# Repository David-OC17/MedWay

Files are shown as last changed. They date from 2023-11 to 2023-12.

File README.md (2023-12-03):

<p align="center">
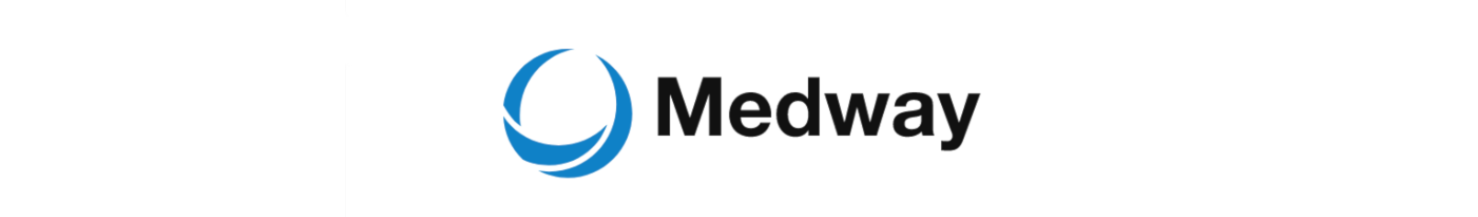
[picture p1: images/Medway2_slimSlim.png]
  
</p>

# MedWay

MedWay: An IoT system for tracking medicines and vaccines from production to use, ensuring their safety and integrity, promoting global health security through transparency and accountability.

## Problem at hand

Ensuring the optimal preservation of medicines and vaccines necessitates strict control over various factors such as temperature and humidity. It is crucial to maintain these conditions to guarantee the products reach their final destination in optimal condition. For pharmaceuticals, particularly those from smaller organizations with limited budgets, effective regulation and tracking become essential to identify instances of mishandling and eliminate potentially compromised batches.

Our proposed system addresses the challenges associated with the mismanagement of vaccines and pharmaceutical drugs, especially prevalent in smaller organizations lacking extensive monitoring infrastructure for their cold chain.

The developed system offers a cost-effective and scalable solution for monitoring batch conditions during transportation. It generates insightful reports to assess potential issues in the transportation process, facilitating the identification and segregation of potentially compromised batches from the rest.

<p align="center">
We combine several technologies and tools in order to produce a valuable and useful system.
</p>

<p align="center">
<a href="https://www.python.org" target="_blank" rel="noreferrer">
python 
</a>
<a href="https://aws.amazon.com/" target="_blank" rel="noreferrer">
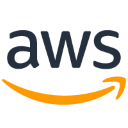
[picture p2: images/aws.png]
 
</a>
<a href="https://flet.dev/" target="_blank" rel="noreferrer">
python 
</a>
<a href="https://platformio.org/" target="_blank" rel="noreferrer">
python 
</a>
<a href="https://xgboost.readthedocs.io/en/stable/#" target="_blank" rel="noreferrer">
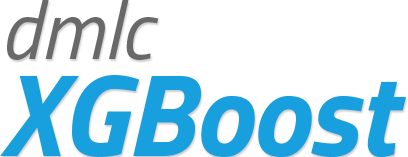
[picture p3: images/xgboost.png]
 
</a>
<a href="https://www.mysql.com/" target="_blank" rel="noreferrer">
python
</a>
<a target="_blank" rel="noopener noreferrer nofollow" href="https://camo.githubusercontent.com/2ecad22021fc13e37458a8d2b508a47352c096930f163927cb191353106f9309/68747470733a2f2f74656368737461636b2d67656e657261746f722e766572636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">
icon
</a>
</p>

## Subparts of the system

### Data acquisition

The data acquisition module is based on a ESP-32 micro-controller, using several sensors to acquire temperature, humidity, acceleration and position. We transfer the data to a computer that acts as a local server using Ubuntu, and temporarily store the data from the N modules running inside medicine/vaccine batches.

<p align="center">
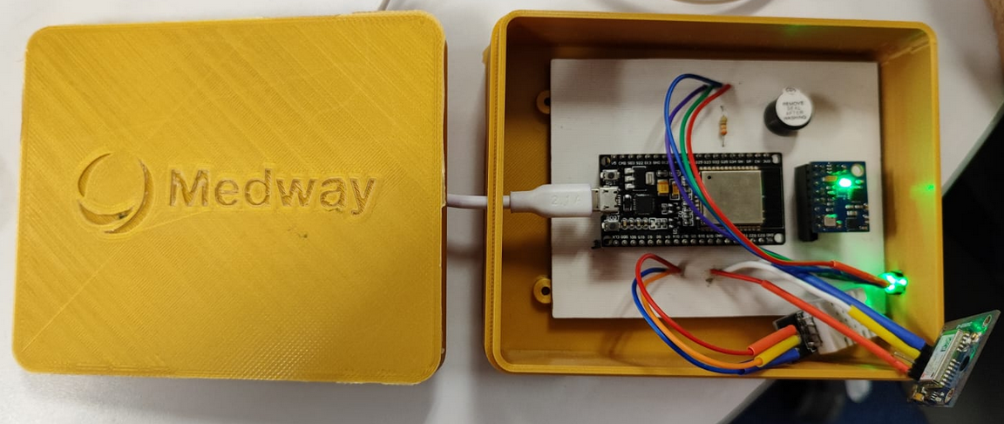
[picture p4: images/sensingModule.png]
  
</p>

### Databases

There are two main types of databases used in this system. The main one is based on MySQL, and is made to be set up on AWS and on a local server. The second one is for storing the reports, result of the daily analysis of data; we use S3 AWS service for this purpose.

### Analysis

The data is analyzed using Lambda functions inside AWS, which run an XGBoost model created via Python. **XGBoost**, short for eXtreme Gradient Boosting, is a powerful and efficient machine learning algorithm that belongs to the ensemble learning category.

<p align="center">
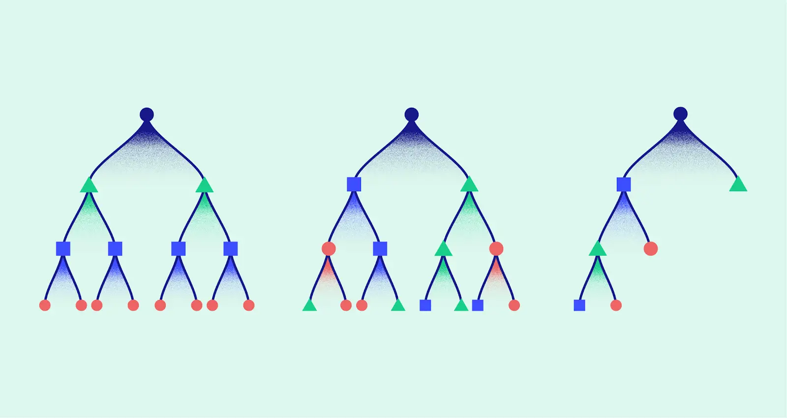
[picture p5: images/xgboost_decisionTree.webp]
  
</p>

The model fits the dataset particularly well, as well as the decisions involved in analyzing the relationships between the main data points of temperature, humidity and UV-light, and its connection to the state of a batch of drugs. Since the connections between the conditions that the batch experiences and the state of the batch itself may be though as a decision tree, where one observes which conditions have been met and which have not, then XGBoost, apart from its robustness, is a good tool for the job.

<!-- Include image of the sensing module, once done -->

### Web and mobile application

The web and mobile app is done via Flet. In the app there are 3 submenus, an introduction, one for downloading the PDF reports, and one that shows a table of the last 30 readings received from the modules.

The app may also be accessed via a phone by generating an QR code that may be scanned using a phone, and will open up the equivalent UI that is generated in the web, inside the Flet app.

## Quick-start guide

To be able to use the implementation developed in this repository you will need to do several things. 

1. Set up your AWS account with the appropriate connections between RDS, S3 and Lambda, in order to run everything on the cloud.

2. Build the physical sensor and receiving modules, from the provided diagram.

3. Install Python3 and all the requirements, via the following command:
```bash
pip3 install -r requirements.txt
```

4. (Optional) Download Flet to your phone (via [AppStore](https://apps.apple.com/mx/app/flet/id1624979699) or PlayStore) in order to be able to access the application from you mobile. Scan the following image to download the app:
<p align="center">
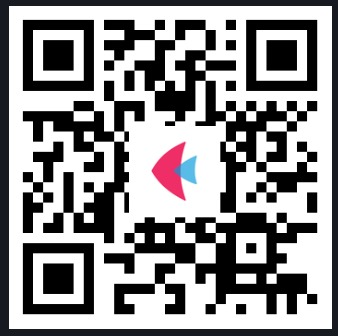
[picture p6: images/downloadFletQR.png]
  
</p>

5. Create `.env` files for saving your passwords and the rest of the variables necessary for connecting to the database services, something with the following type of format:
```python
CLOUD_HOST = 'aws.host.access_point/...'
CLOUD_USER = 'user'
CLOUD_PASSWORD = '123ABC'
# continue declaring the variables
```

6. Create the database for temporary data saving.

7. Create the necessary tables inside the two databases.
```bash
cd databases
python3 createSQL.py
```
8. Set up the WiFi connection to the sensing module and start pulling data. 

9. Wait for the main actions to occur, sending information to the cloud database, generating the reports and seeing the results via the web/mobile app.

To familiarize yourself with the whole system, use the tests inside the `./test/` directory. Also, use the tests to try your local set-up before trying to run the complete system.

<!-- ## Testing

### AWS
In order to test the deployment of the Lambda function before uploading to AWS you may use the [SAM](https://docs.aws.amazon.com/serverless-application-model/latest/developerguide/install-sam-cli.html) locally. -->

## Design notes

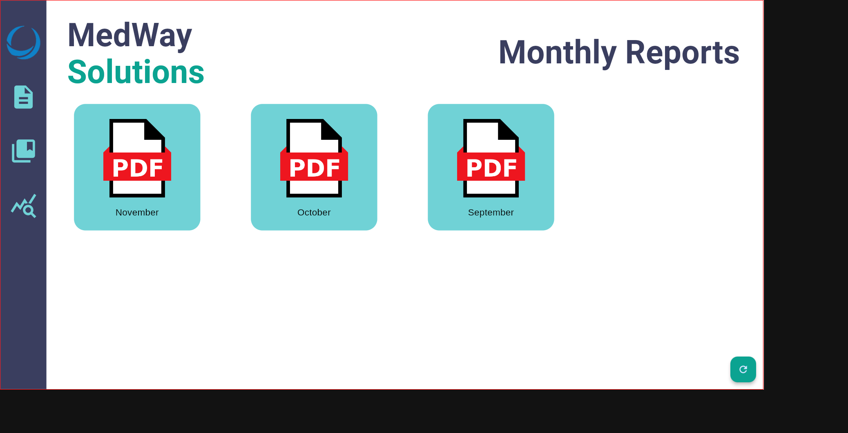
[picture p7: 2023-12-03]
images/monthly_reports.png

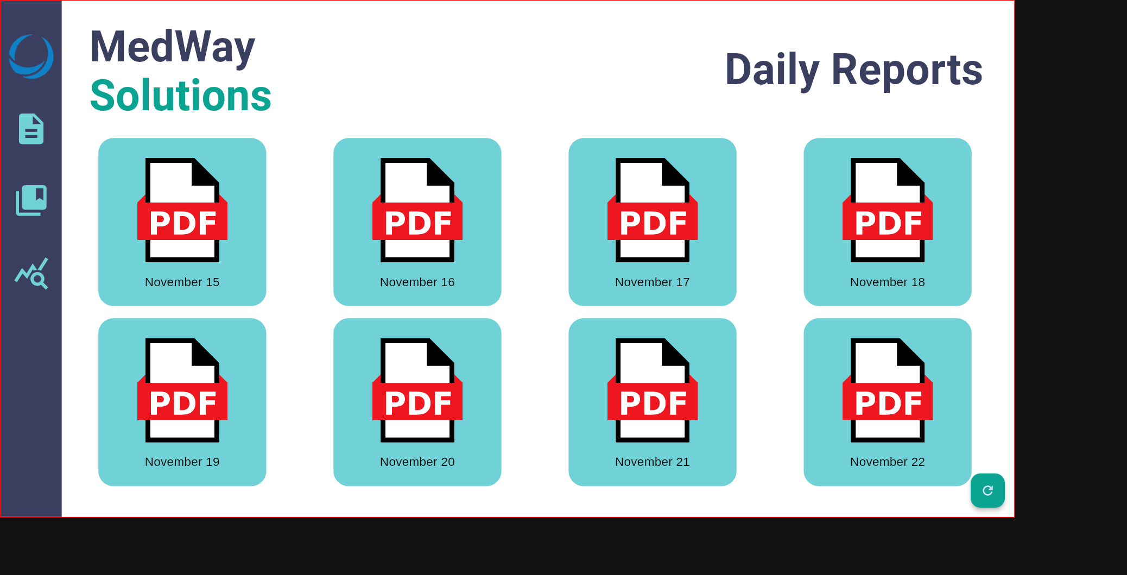
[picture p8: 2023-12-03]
images/daily_reports.png

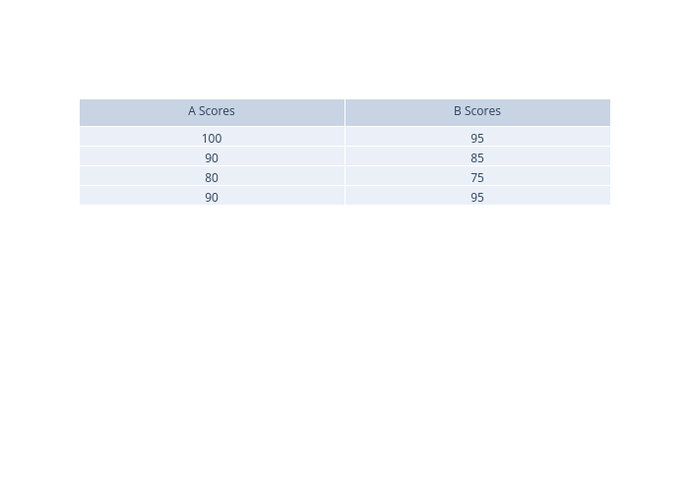
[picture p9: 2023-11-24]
test/reportGenerator/table_image.png

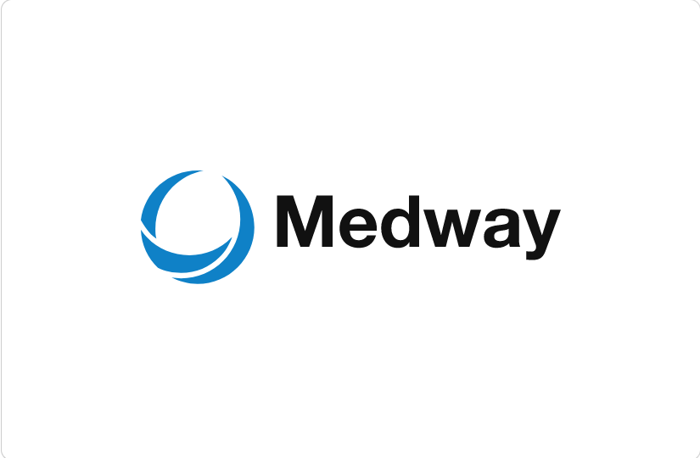
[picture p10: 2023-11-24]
images/Medway2.png

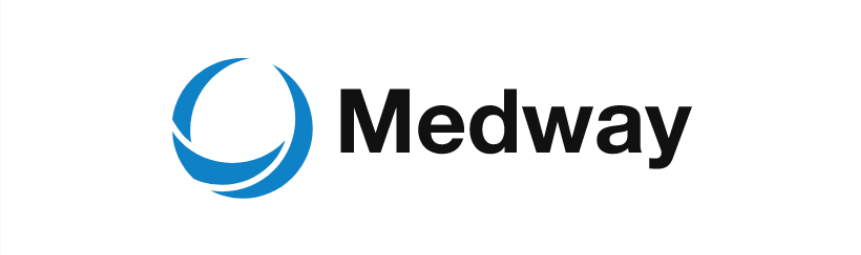
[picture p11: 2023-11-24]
images/Medway2_slim.png

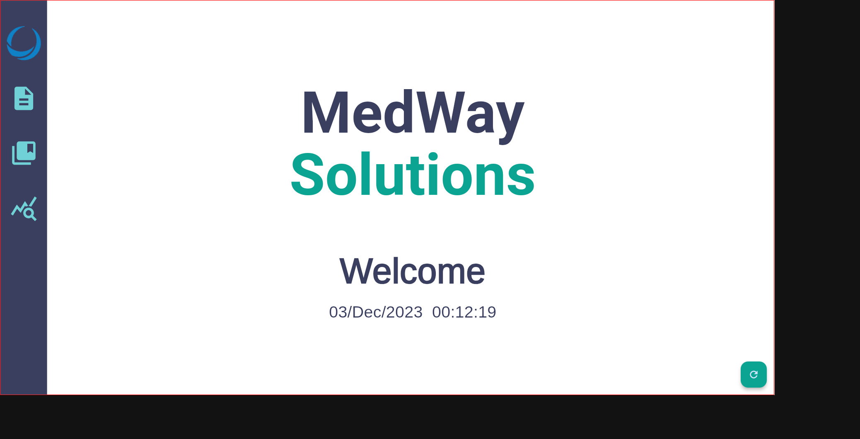
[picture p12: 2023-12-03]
images/home.png

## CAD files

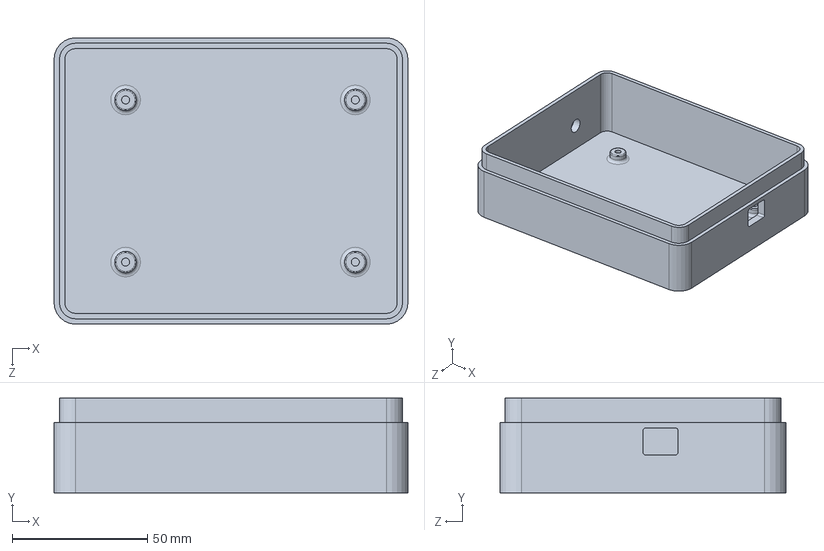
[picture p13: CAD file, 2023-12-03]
dataAcquisition/PCB/SolidCase/Case.SLDPRT
131.0 x 35.0 x 106.0 mm

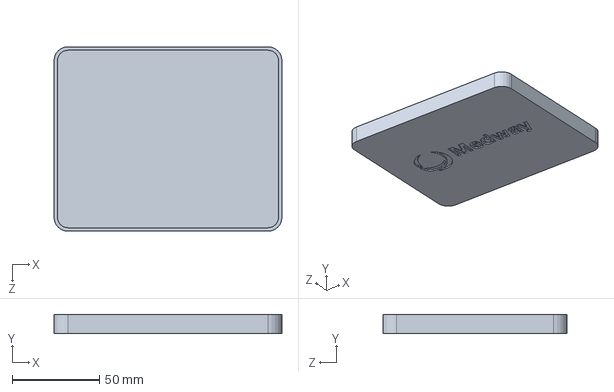
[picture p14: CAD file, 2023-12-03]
dataAcquisition/PCB/SolidCase/Top.SLDPRT
131.0 x 11.0 x 106.0 mm

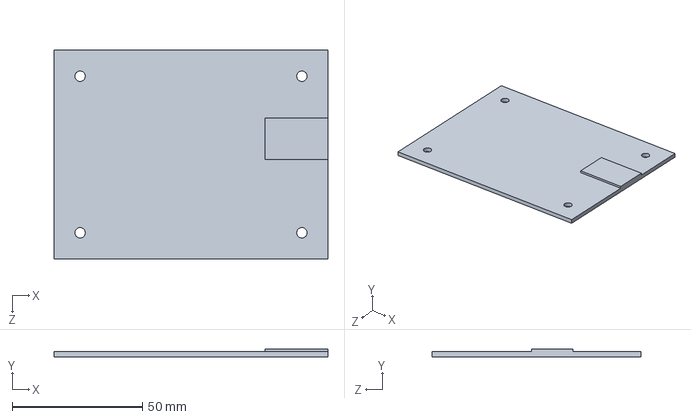
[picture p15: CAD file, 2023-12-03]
dataAcquisition/PCB/SolidCase/Baquela.SLDPRT
105.0 x 3.00 x 80.0 mm

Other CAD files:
dataAcquisition/PCB/SolidCase/Case.STL
dataAcquisition/PCB/SolidCase/Top.STL

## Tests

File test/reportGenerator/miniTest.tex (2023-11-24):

% Use this simple file in order to test basic compilation capabilities of pdflatex in your computer/server

\documentclass{article}
\usepackage{hyperref}
\begin{document}
Hello world \LaTeX

\url{https://linuxconfig.org}
\end{document}

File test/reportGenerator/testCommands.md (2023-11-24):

# Test commands for LaTeX report creation

## Quick test

Compile the `miniTest.tex` file present in this directory by using the command:
```bash
pdflatex -shell-escape miniTest.tex
```

## More extense test

To be able to create the `.pdf` files as needed, verify that `pdflatex` command is working by
compiling the `dailyReportTemplate_test.tex` file present in this directory. (Temporarly take the file to `/analysis/templates/` to avoid having to pass the contents of the placeholders if so is needed, and avoiding having to change the routes to the images.) Run the following command from the terminal:
```bash
# If in Linux
pdflatex -shell-escape dailyReportTemplate_test.tex

# If in Windows
pdflatex dailyReportTemplate_test.tex
```

_Note:_ to test full compilation (with placeholders included) from Python3, run the `reportGenerator.py` file.

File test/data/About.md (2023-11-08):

# Test data

Save testing data only in this directory. 
To generate more data, use /randomTestData/generate_random_data.py

_This file is included in order for the data/ directory to show in the repository._

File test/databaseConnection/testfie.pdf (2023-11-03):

# TEST FILE

Test connection to the cloud by uploading this file. Remove after

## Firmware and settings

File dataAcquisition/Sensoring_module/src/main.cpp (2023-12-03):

#include <Arduino.h>
#include <DHT.h>
#include <TinyGPS++.h>
#include "MPU6050_6Axis_MotionApps20.h"
#include "WiFi.h"

// MACROS
#define DHT_PIN 4
#define DHTTYPE DHT22
#define MPU_INTERRUPT_PIN 27
#define EN_LED 0
#define RED 27
#define GREEN 14
#define BLUE 12
#define BUZZER 13
 
// Constants
const int time2send = 3000;
const int time2sample_dht = 1000;

// Flags
bool wifi_connected = false;
bool mpu_connected = false;

// Sensores
DHT dht(DHT_PIN, DHTTYPE, 22);
TinyGPSPlus gps;
MPU6050 mpu;

// GLOBAL VARS FOR TELEMETRY //
// DHT vars
float hum, temp;

// GPS vars
float lat, lon;
float meters = 0;
uint8_t sats = 0;

// MPU Control vars
bool dmp_ready = false;
uint8_t device_status;
uint8_t interrupt_status;
uint8_t fifoBuffer[64];
uint16_t packet_size;
uint16_t fifo_count;

// DMP Vars
Quaternion q;
VectorInt16 aa;     // Raw acceleration from the sensor
VectorInt16 aaReal;
VectorFloat gravity;
float ypr[3];       // Yaw, Pitch, Roll
float average_array[50];
float mean_accel;
uint8_t accel_count;

// Time management
unsigned long time_aux = 0;

// Send data
String data = "";

///// MPU INTERRUPT /////////////////////////
volatile bool mpu_interrupt = false;
void dmpDataReady(){
  mpu_interrupt = true;
}
/////////////////////////////////////////////

void getGpsInfo(){
  char c = Serial2.read();
      if (gps.encode(c)){   // If a valid sentence comes in get data
        lat = gps.location.lat();
        lon = gps.location.lng();
        meters = gps.altitude.meters();
        sats = gps.satellites.value();
      }
}

void getMpuData(){
  // If dmp was configured succesfully read available packet to fifo buffer
  if(mpu.dmpGetCurrentFIFOPacket(fifoBuffer)){
      // Get yaw/pitch/roll in array
      mpu.dmpGetQuaternion(&q, fifoBuffer);
      mpu.dmpGetGravity(&gravity, &q);
      mpu.dmpGetYawPitchRoll(ypr, &q, &gravity);

      // Get acceleration
      mpu.dmpGetAccel(&aa, fifoBuffer);
      mpu.dmpGetLinearAccel(&aaReal, &aa, &gravity);   // For our needs aaReal is better because it depreciates the constant effect of gravity
      
      // Average
      mean_accel = (aaReal.x + aaReal.y + aaReal.z) / 3;
  }
}

void updateRGBStat(){
  if(wifi_connected && mpu_connected){
    Serial.println("All working fine");
    analogWrite(RED, 0);     // GREEN (working fine)
    analogWrite(GREEN, 255);
    analogWrite(BLUE, 0);
  }else if(wifi_connected && !mpu_connected){
    analogWrite(RED, 255);     // PURPLE
    analogWrite(GREEN, 0);
    analogWrite(BLUE, 255);
  }else if(!wifi_connected && mpu_connected){
    analogWrite(RED, 0);     // GREEN UPDATE
    analogWrite(GREEN, 255);
    analogWrite(BLUE, 0);
  }else{
    analogWrite(RED, 255);   // RED (nothing works)
    analogWrite(GREEN, 0);
    analogWrite(BLUE, 0);
  }
}

//////////////////////////////////////////

void setup() {
  // UART channels
  Serial.begin(115200);
  Serial2.begin(9600);

  // I2C communication
  Wire.begin();

  // DHT temperature sensor
  dht.begin();

  // Enable LEDS
  pinMode(BUZZER, OUTPUT);
  pinMode(EN_LED, OUTPUT);
  pinMode(RED, OUTPUT);
  pinMode(GREEN, OUTPUT);
  pinMode(BLUE, OUTPUT);

  // MPU and DMP init
  // Serial.println(mpu.testConnection()? "MPU connected succesfully" : "MPU failed to connect");
  device_status = mpu.dmpInitialize();

  // Blue while calibrating
  analogWrite(BLUE, 255);
  analogWrite(RED, 0);
  analogWrite(GREEN, 0);

  // Start sound !
  while(millis() < 2500){
    digitalWrite(BUZZER, HIGH);
  }
  
  digitalWrite(BUZZER, LOW);

  // MPU DMP status handling
  if(device_status == 0){
    mpu_connected = true;
    mpu.setDMPEnabled(true);

    // Calibrate 
    mpu.CalibrateAccel(7);
    mpu.CalibrateGyro(7);

    // Config interrupt
    attachInterrupt(digitalPinToInterrupt(MPU_INTERRUPT_PIN), dmpDataReady, RISING);
    interrupt_status = mpu.getIntStatus();

    // Update dmp ready flag to true
    Serial.println("\nMPU DMP is ready to use");
    // dmp_ready = true;
    
    packet_size = mpu.dmpGetFIFOPacketSize();  // Expected packet size for dmp
  }else{
    // Error: 1 = Initial memory load failed, 2 = DMP configuration updates failed
    Serial.println("DMP config failed with code " + String(device_status));
    mpu_connected = false;
  }
  
  // Update RGB LED as flag
  updateRGBStat();
}

/////////////////////////////////////////////

void loop() {
  // While there is no available data from MPU
  if(millis() - time_aux >= time2send){
    // DHT section
    hum = dht.readHumidity();
    temp = dht.readTemperature();

    // GPS Section
    while (Serial2.available())
    {
      // Get currently available info in serial2 from gps
      getGpsInfo();
    }

    // PRINT DATA
    // Serial.println("Temperature: " + String(temp));
    // Serial.println("Humidity: " + String(hum));
    // Serial.println("Longitude: " + String(lon));
    // Serial.println("Latitude: " + String(lat));
    // Serial.println("Altitude: " + String(meters));
    // Serial.println("Acceleration: " + String(aaReal.x) + " " + String(aaReal.y) + " " + String(aaReal.z));
    // Serial.println("Gyroscope: " + String(ypr[0] * 180/M_PI) + " " + String(ypr[1] * 180/M_PI) + " " + String(ypr[2] * 180/M_PI) + "\n");

    // data = String(temp) + "," + String(hum) + "," + String(lon) + "," + String(lat) + "," + String(meters) + "," + 
    //        String(aaReal.x) + "," + String(aaReal.y) + "," + String(aaReal.z) + "," + String(ypr[0] * 180/M_PI) + "," 
    //        + String(ypr[1] * 180/M_PI) + "," + String(ypr[2] * 180/M_PI);
    
    data = String(lon) + "," + String(lat) + "," + String(temp) + "," + String(hum);

    Serial.println(data);

    time_aux = millis();
  }

  // Get MPU data
  if(mpu_connected){
    getMpuData();
  }

  // Manage bad orientation
  if(ypr[2] * 180/M_PI >= 90 || ypr[3] * 180/M_PI >= 90){
    // Serial.println("BAd orientatioon!");
    digitalWrite(BUZZER, HIGH);
  }else{
    digitalWrite(BUZZER, LOW);
  }

  // if(aaReal.x >= 10000 || aaReal.y >= 10000 || aaReal.z >= 10000){
  //   // Serial.println("BAd orientatioon!");
  //   digitalWrite(BUZZER, HIGH);
  // }else{
  //   digitalWrite(BUZZER, LOW);
  // }

  delay(100);
}

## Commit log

2023-10-13 Added PlatformIO workspace for ESP32 sensoring module development
2023-11-03 Combined sensor data table and batch position, added S3 connection to bucket test, added S3 cloud manager
2023-11-04 Added random data generator for testing
    [test_data.csv]
2023-11-06 Connection to localhost working, rearranged test files
    [test_data.csv]
2023-11-10 Name replacing in some files and other minor changes
    [sensor_data.csv]
2023-11-14 Minor changes to tests
    [sensor_data.csv]
2023-11-21 Added script for MPU calibration
2023-11-22 Getting acceleration and orientation correctly with dmp
    [main.cpp]
2023-11-22 All sensors working fine
2023-11-22 WiFi connection working, client handling not yet
    [IOT_PCB.sch]
2023-11-23 Added S3 bucket connection
2023-11-23 Specified the region where the bucket is located
2023-12-01 PCB and solidworks files
    [Baquela.SLDPRT, Case.SLDPRT, Case.STL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]
2023-12-01 Connected to official S3 bucket
